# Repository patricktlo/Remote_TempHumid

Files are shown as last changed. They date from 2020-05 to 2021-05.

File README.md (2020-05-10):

 # Remote TempHumid sensor

Using a simple STM32F030 MCU with a temperature sensor (TBD) and a relative humidity sensor (TBD), coupled with optional Wifi (ESP-01) or LoRa (RA-01) connectivity.

Initially this project is aimed to measure the conditions of a wine cellar, ideal stats include temperature around 12 C and RH 50-80%. But this board is designed to be versatile and could be used anywhere.

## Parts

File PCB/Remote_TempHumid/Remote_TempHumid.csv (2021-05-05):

Comment | Designator | Footprint | LCSC | Field4 | Field5 | Field6
BK-18650-PC2 | BT1 | 18650_Connector:BAT_BK-18650-PC2 |  | Manufacturer Recommendations | 21.41 mm | MPD
10u | C12,C13 | Capacitor_SMD:C_0805_2012Metric | C15850
4.7u | C3,C15,C17 | Capacitor_SMD:C_0603_1608Metric | C19666
12p | C6,C7,C5,C2 | Capacitor_SMD:C_0603_1608Metric | C38523
100n | C8,C4,C1,C14,C16,C10 | Capacitor_SMD:C_0603_1608Metric | C14663
1u | C9,C11 | Capacitor_SMD:C_0805_2012Metric | C28323
D_Schottky | D4,D2,D3 | Diode_SMD:D_SMA | C2480
LED | D5,D1 | LED_SMD:LED_0603_1608Metric | C2290
Conn_01x05_Male | J1 | Connector_PinHeader_2.54mm:PinHeader_1x05_P2.54mm_Vertical
Conn_02x04_Odd_Even | J2 | Connector_PinHeader_2.54mm:PinHeader_2x04_P2.54mm_Vertical
C10418 | J3 | Custom_lib:C10418 | C10418
Conn_01x02_Female | J4 | Connector_PinSocket_2.54mm:PinSocket_1x02_P2.54mm_Vertical
Q_PMOS_GSD | Q1 | Package_TO_SOT_SMD:SOT-23W | C15127
Q_NMOS_GSD | Q2,Q3 | Package_TO_SOT_SMD:SOT-23W | C20917
10k | R1,R10,R11,R12 | Resistor_SMD:R_0603_1608Metric | C25804
22 | R13,R14 | Resistor_SMD:R_0603_1608Metric | C23345
1k | R15,R5,R7 | Resistor_SMD:R_0603_1608Metric | C21190
390 | R2 | Resistor_SMD:R_0603_1608Metric | C23151
4.7k | R4,R3 | Resistor_SMD:R_0603_1608Metric | C23162
2.2k | R6 | Resistor_SMD:R_0603_1608Metric | C4190
470 | R8 | Resistor_SMD:R_0603_1608Metric | C23179
1.5k | R9 | Resistor_SMD:R_0603_1608Metric | C22843
VIN_TP | TP10 | TestPoint:TestPoint_Pad_D1.5mm
TestPoint | TP4,TP3 | TestPoint:TestPoint_Pad_D1.5mm
STM32F103C8Tx | U1 | Package_QFP:LQFP-48_7x7mm_P0.5mm | C8734
SHT21 | U2 | SHT20:DFN300X300X110-7N | C84828
TP4054 | U3 | Package_TO_SOT_SMD:SOT-23-5 | C32574
FS8205 | U4 | Package_TO_SOT_SMD:SOT-23-6 | C32254
DW01+G | U5 | Package_TO_SOT_SMD:SOT-23-6 | C14213
ESP-01 | U6 | ESP8266:ESP-01
Ai-Thinker-Ra-01 | U7 | RF_Module:Ai-Thinker-Ra-01-LoRa
HT75xx-1-SOT89 | U8 | Package_TO_SOT_SMD:SOT-89-3 | C14289
32.768 kHz | Y1 | Crystal:Crystal_SMD_3215-2Pin_3.2x1.5mm | C32346
12MHz | Y2 | Crystal:Crystal_SMD_3225-4Pin_3.2x2.5mm | C9002

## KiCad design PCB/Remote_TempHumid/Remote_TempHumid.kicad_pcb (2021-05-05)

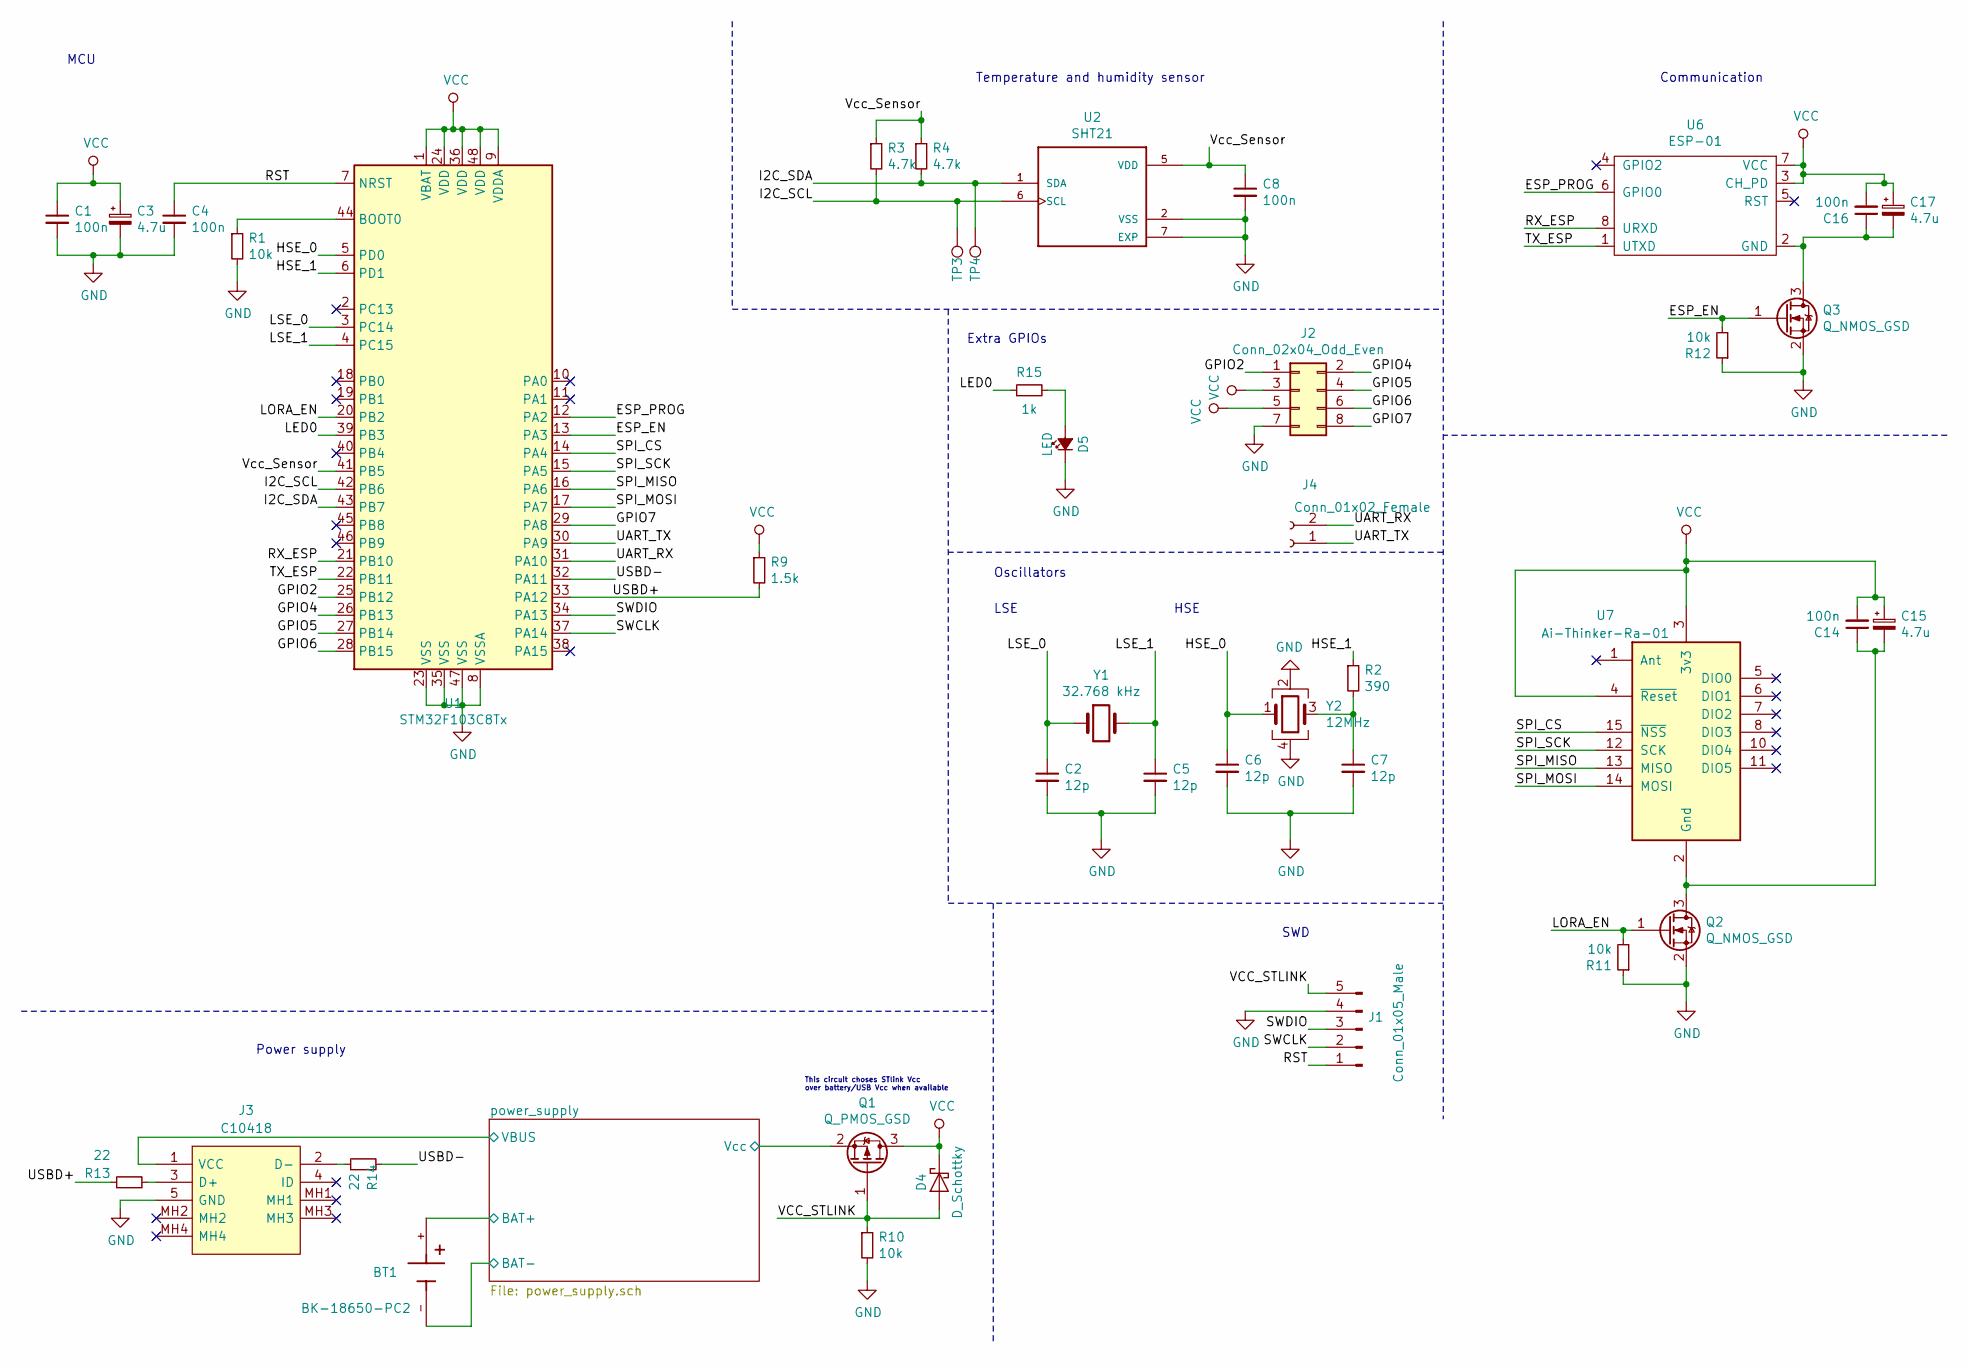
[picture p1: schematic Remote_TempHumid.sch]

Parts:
BT1: BK-18650-PC2; BAT_BK-18650-PC2
C1, C4, C8, C14, C16: 100n; C_0603_1608Metric; LCSC C14663
C2, C5, C6, C7: 12p; C_0603_1608Metric; LCSC C38523
C3, C15, C17: 4.7u; C_0603_1608Metric; LCSC C19666
D4: D_Schottky; D_SMA; LCSC C2480
D5: LED; LED_0603_1608Metric; LCSC C2290
J1: Conn_01x05_Male; PinHeader_1x05_P2.54mm_Vertical
J2: Conn_02x04_Odd_Even; PinHeader_2x04_P2.54mm_Vertical
J3: C10418; LCSC C10418
J4: Conn_01x02_Female; PinSocket_1x02_P2.54mm_Vertical
Q1: Q_PMOS_GSD; SOT-23W; LCSC C15127
Q2, Q3: Q_NMOS_GSD; SOT-23W; LCSC C20917
R1, R10, R11, R12: 10k; R_0603_1608Metric; LCSC C25804
R2: 390; R_0603_1608Metric; LCSC C23151
R3, R4: 4.7k; R_0603_1608Metric; LCSC C23162
R9: 1.5k; R_0603_1608Metric; LCSC C22843
R13, R14: 22; R_0603_1608Metric; LCSC C23345
R15: 1k; R_0603_1608Metric; LCSC C21190
TP3, TP4: TestPoint; TestPoint_Pad_D1.5mm
U1: STM32F103C8Tx; LQFP-48_7x7mm_P0.5mm; LCSC C8734
U2: SHT21; DFN300X300X110-7N; LCSC C84828
U6: ESP-01
U7: Ai-Thinker-Ra-01; Ai-Thinker-Ra-01-LoRa
Y1: 32.768 kHz; Crystal_SMD_3215-2Pin_3.2x1.5mm; LCSC C32346
Y2: 12MHz; Crystal_SMD_3225-4Pin_3.2x2.5mm; LCSC C9002

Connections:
/ESP_EN: Q3.1 (G), R12.2, U1.13 (PA3)
/ESP_PROG: U1.12 (PA2), U6.6 (GPIO0)
/GPIO2: J2.1, U1.25 (PB12)
/GPIO4: J2.2, U1.26 (PB13)
/GPIO5: J2.4, U1.27 (PB14)
/GPIO6: J2.6, U1.28 (PB15)
/GPIO7: J2.8, U1.29 (PA8)
/HSE_0: C6.1, U1.5 (PD0), Y2.1
/HSE_1: R2.1, U1.6 (PD1)
/I2C_SCL: R3.2, TP3.1, U1.42 (PB6), U2.6 (SCL)
/I2C_SDA: R4.2, TP4.1, U1.43 (PB7), U2.1 (SDA)
/LED0: R15.1, U1.39 (PB3)
/LORA_EN: Q2.1 (G), R11.2, U1.20 (PB2)
/LSE_0: C2.1, U1.3 (PC14), Y1.1
/LSE_1: C5.1, U1.4 (PC15), Y1.2
/RST: C4.1, J1.1, U1.7 (NRST)
/RX_ESP: U1.21 (PB10), U6.8 (URXD)
/SPI_CS: U1.14 (PA4), U7.15 (~NSS)
/SPI_MISO: U1.16 (PA6), U7.13 (MISO)
/SPI_MOSI: U1.17 (PA7), U7.14 (MOSI)
/SPI_SCK: U1.15 (PA5), U7.12 (SCK)
/SWCLK: J1.2, U1.37 (PA14)
/SWDIO: J1.3, U1.34 (PA13)
/TX_ESP: U1.22 (PB11), U6.1 (UTXD)
/UART_RX: J4.2, U1.31 (PA10)
/UART_TX: J4.1, U1.30 (PA9)
/USBD+: R9.2, R13.1, U1.33 (PA12)
/USBD-: R14.2, U1.32 (PA11)
/VCC_STLINK: D4.2 (A), J1.5, Q1.1 (G), R10.1
/Vcc_Sensor: C8.1, R3.1, R4.1, U1.41 (PB5), U2.5 (VDD)
/power_supply/BAT+: BT1.+; also elsewhere on the board
/power_supply/BAT-: BT1.-; also elsewhere on the board
/power_supply/VBUS: J3.1 (VCC); also elsewhere on the board
/power_supply/Vcc: Q1.2 (S); also elsewhere on the board
GND: C1.2, C2.2, C3.2, C4.2, C5.2, C6.2, C7.2, C8.2, D5.1 (K), J1.4, J2.7, J3.5 (GND), Q2.2 (S), Q3.2 (S), R1.2, R10.2, R11.1, R12.1, U1.8 (VSSA), U1.23 (VSS), U1.35 (VSS), U1.47 (VSS), U2.2 (VSS), U2.7 (EXP), Y2.2, Y2.4; also elsewhere on the board
unnamed: C7.1, R2.2, Y2.3
unnamed: C14.1, C15.2, Q2.3 (D), U7.2 (Gnd), U7.9 (Gnd), U7.16 (Gnd)
unnamed: C16.1, C17.2, Q3.3 (D), U6.2 (GND)
unnamed: D5.2 (A), R15.2
unnamed: J3.2 (D-), R14.1
unnamed: J3.3 (D+), R13.2
unnamed: R1.1, U1.44 (BOOT0)
VCC: C1.1, C3.1, C14.2, C15.1, C16.2, C17.1, D4.1 (K), J2.3, J2.5, Q1.3 (D), R9.1, U1.1 (VBAT), U1.9 (VDDA), U1.24 (VDD), U1.36 (VDD), U1.48 (VDD), U6.3 (CH_PD), U6.7 (VCC), U7.3 (3v3), U7.4 (~Reset)

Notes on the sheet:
Communication
Temperature and humidity sensor
MCU
Power supply
SWD
Oscillators
LSE
HSE
This circuit choses STlink Vcc over battery/USB Vcc when available
Extra GPIOs

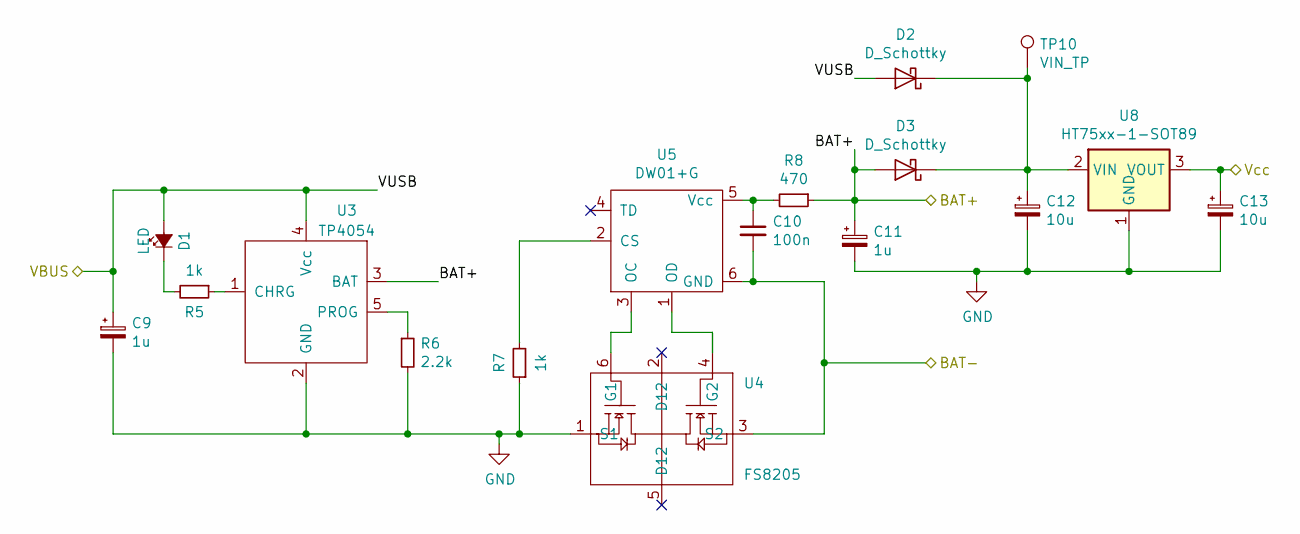
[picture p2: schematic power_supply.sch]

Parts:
C9, C11: 1u; C_0805_2012Metric; LCSC C28323
C10: 100n; C_0603_1608Metric; LCSC C14663
C12, C13: 10u; C_0805_2012Metric; LCSC C15850
D1: LED; LED_0603_1608Metric; LCSC C72041
D2, D3: D_Schottky; D_SMA; LCSC C2480
R5, R7: 1k; R_0603_1608Metric; LCSC C21190
R6: 2.2k; R_0603_1608Metric; LCSC C4190
R8: 470; R_0603_1608Metric; LCSC C23179
TP10: VIN_TP; TestPoint_Pad_D1.5mm
U3: TP4054; SOT-23-5; LCSC C32574
U4: FS8205; SOT-23-6; LCSC C32254
U5: DW01+G; SOT-23-6; LCSC C14213
U8: HT75xx-1-SOT89; SOT-89-3; LCSC C14289

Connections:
/power_supply/BAT+: C11.1, D3.2 (A), R8.1, U3.3 (BAT); also elsewhere on the board
/power_supply/BAT-: C10.2, U4.3 (S2), U5.6 (GND); also elsewhere on the board
/power_supply/VBUS: C9.1, D1.2 (A), D2.2 (A), U3.4 (Vcc); also elsewhere on the board
/power_supply/Vcc: C13.1, U8.3 (VOUT); also elsewhere on the board
GND: C9.2, C11.2, C12.2, C13.2, R6.2, R7.1, U3.2 (GND), U4.1 (S1), U8.1 (GND); also elsewhere on the board
unnamed: C10.1, R8.2, U5.5 (Vcc)
unnamed: C12.1, D2.1 (K), D3.1 (K), TP10.1, U8.2 (VIN)
unnamed: D1.1 (K), R5.2
unnamed: R5.1, U3.1 (CHRG)
unnamed: R6.1, U3.5 (PROG)
unnamed: R7.2, U5.2 (CS)
unnamed: U4.4 (G2), U5.1 (OD)
unnamed: U4.6 (G1), U5.3 (OC)

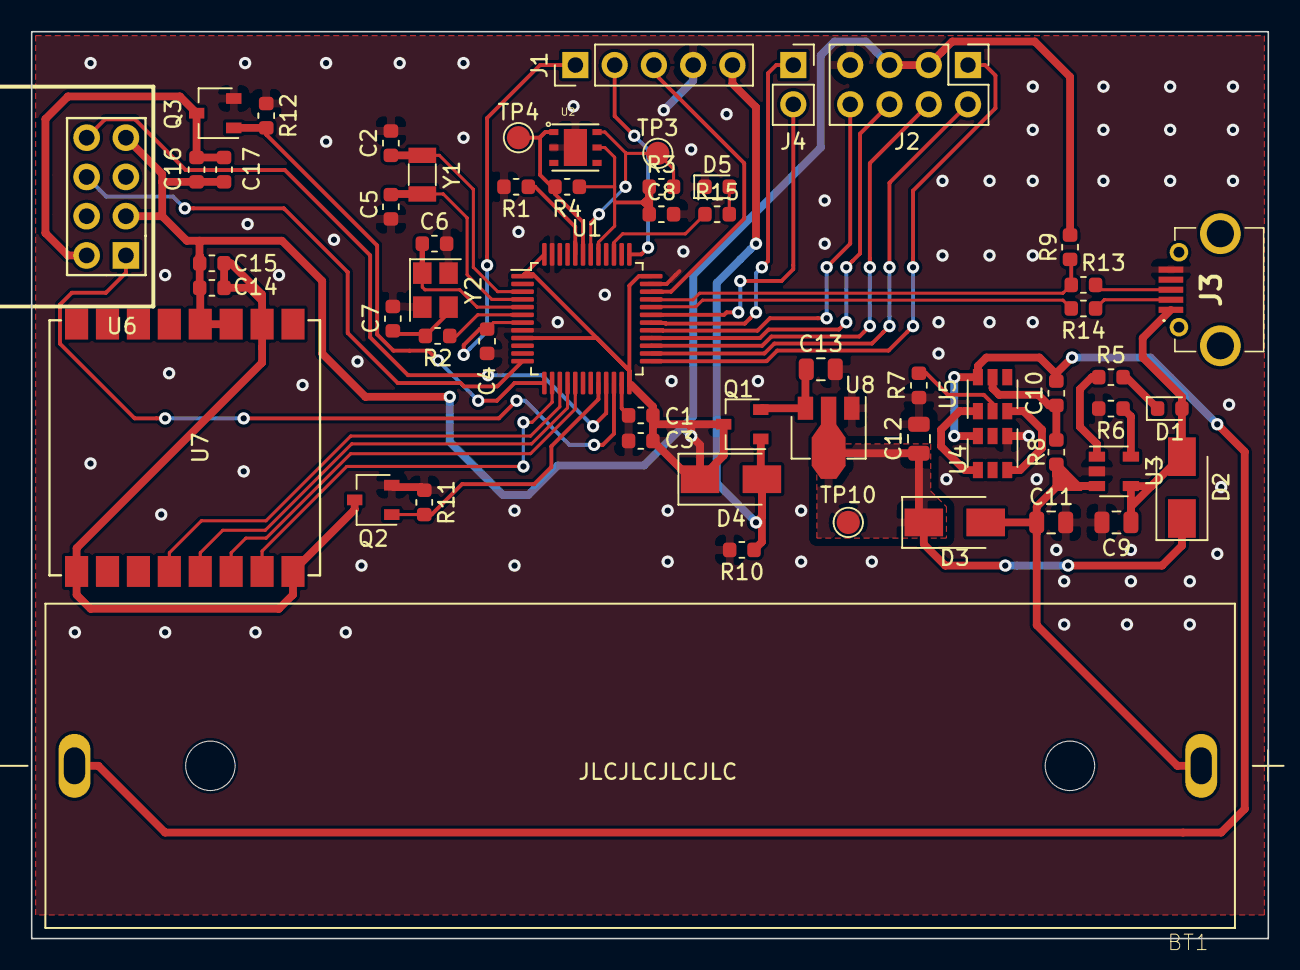
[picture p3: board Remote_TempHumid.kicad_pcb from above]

Board: 2 copper layers, 80.0 x 58.7 mm, 58 parts (0 on the bottom side), 51 nets.

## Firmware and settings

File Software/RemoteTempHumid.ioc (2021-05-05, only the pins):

Mcu.UserName=STM32F103C8Tx
PA10.Signal=USART1_RX
PA11.Signal=USB_DM
PA12.Signal=USB_DP
PA13.Signal=SYS_JTMS-SWDIO
PA14.Signal=SYS_JTCK-SWCLK
PA3.GPIO_Label=LORA_EN
PA3.Signal=GPIO_Output
PA4.Signal=SPI1_NSS
PA5.Signal=SPI1_SCK
PA6.Signal=SPI1_MISO
PA7.Signal=SPI1_MOSI
PA9.Signal=USART1_TX
PB10.Signal=USART3_TX
PB11.Signal=USART3_RX
PB12.GPIO_Label=ESP_PROG
PB12.Signal=GPIO_Output
PB2.GPIO_Label=ESP_EN
PB2.Signal=GPIO_Output
PB3.GPIO_Label=LED0
PB3.Signal=GPIO_Output
PB5.GPIO_Label=Vcc_Sensor
PB5.Signal=GPIO_Output
PB6.Signal=I2C1_SCL
PB7.Signal=I2C1_SDA
PC14-OSC32_IN.Signal=RCC_OSC32_IN
PC15-OSC32_OUT.Signal=RCC_OSC32_OUT
PD0-OSC_IN.Signal=RCC_OSC_IN
PD1-OSC_OUT.Signal=RCC_OSC_OUT

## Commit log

2020-05-10 started PCB and cubemx project
    [Remote_TempHumid.kicad_pcb, Remote_TempHumid.sch]
2021-05-05 up to date with old ubuntu
    [Remote_TempHumid-B_Cu.gbr, Remote_TempHumid-B_Mask.gbr, Remote_TempHumid-B_SilkS.gbr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]
